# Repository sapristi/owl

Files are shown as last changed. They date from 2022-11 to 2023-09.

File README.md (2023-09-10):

# The Owl

the owl

The Owl is a 36-key (diodeless!), MX-spaced, wireless keyboard.

It was forked from the [rae-dux](https://github.com/andrewjrae/rae-dux) (itself inspired by the [Architeuthis Dux](https://github.com/tapioki/cephalopoda/tree/main/Architeuthis%20dux) ).

The main difference with the rae-dux is that MX-spacing is used for the keys. This keyboard is also designed with top and bottom plates, so as to protect the MCU and the battery. The mounting holes will fit m3 screws / standoffs.

**Note**: the top-plate doesn't need the mounting holes, so you could remove them from the kicad files.

## Art

The art for the keyboard is from vecteezy.com:
 - top was adapted from https://www.vecteezy.com/vector-art/2531138-black-and-white-line-art-of-owl
 - bottom was adapted from https://www.vecteezy.com/vector-art/3378572-barn-owl-flying-over-black-background

## Firmware

Since the keyboard is the same as the rae-dux, you can use the rae-dux firmware for it, see e.g.
- [my rae-dux ZMK config](https://github.com/sapristi/zmk-config-rae-dux)
- the original [rae-dux ZMK shield](https://github.com/andrewjrae/zmk-config/tree/development/config/boards/shields/rae_dux) (note: this is configured to use an older zmk version, with some bugs on mod-tap)

## Build Guide

Checkout the build-guide for the [rae-dux](./build_guide/index.md). The main difference is that the MCUs are mounted on the bottom of the PCBs.

A small thing you can change is also to put power switche on different sides of the pcb, so that both are in the same position for on-off.

## Important Notes
- **Wireless only**, the 36-key diodeless approach uses the P0 pin which is usually dedicated to TRRS
- There is only one MCU footprint, so **one controller has to be flipped**
- If you want to skip out on the switch, there is no jumper to use the JST
  connector, so you'll have to bodge a wire somewhere, or try shorting the
  switch footprint.

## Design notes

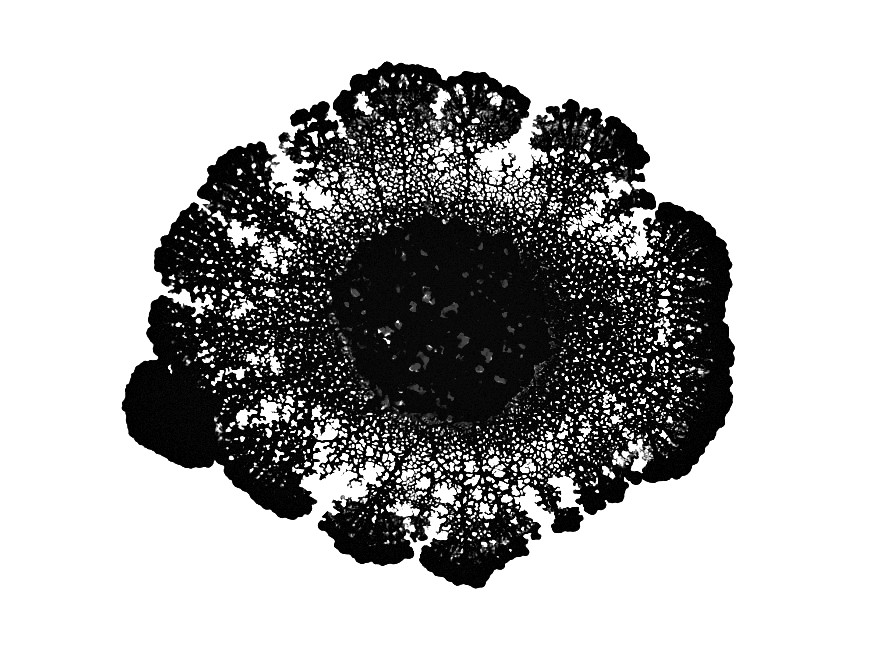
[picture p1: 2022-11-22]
images/blob.jpg

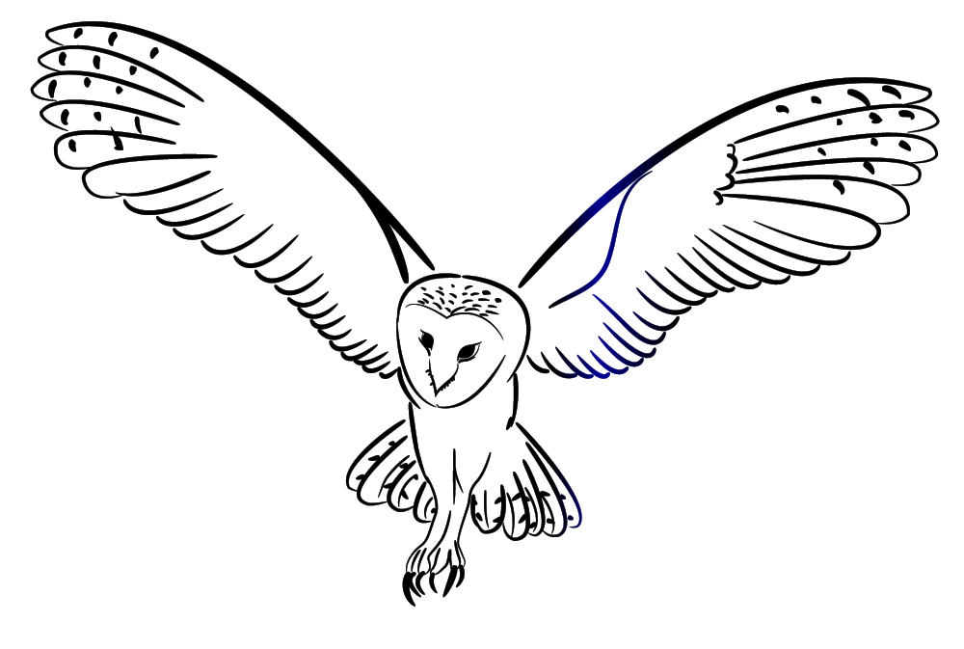
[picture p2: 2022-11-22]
images/owl_back.png

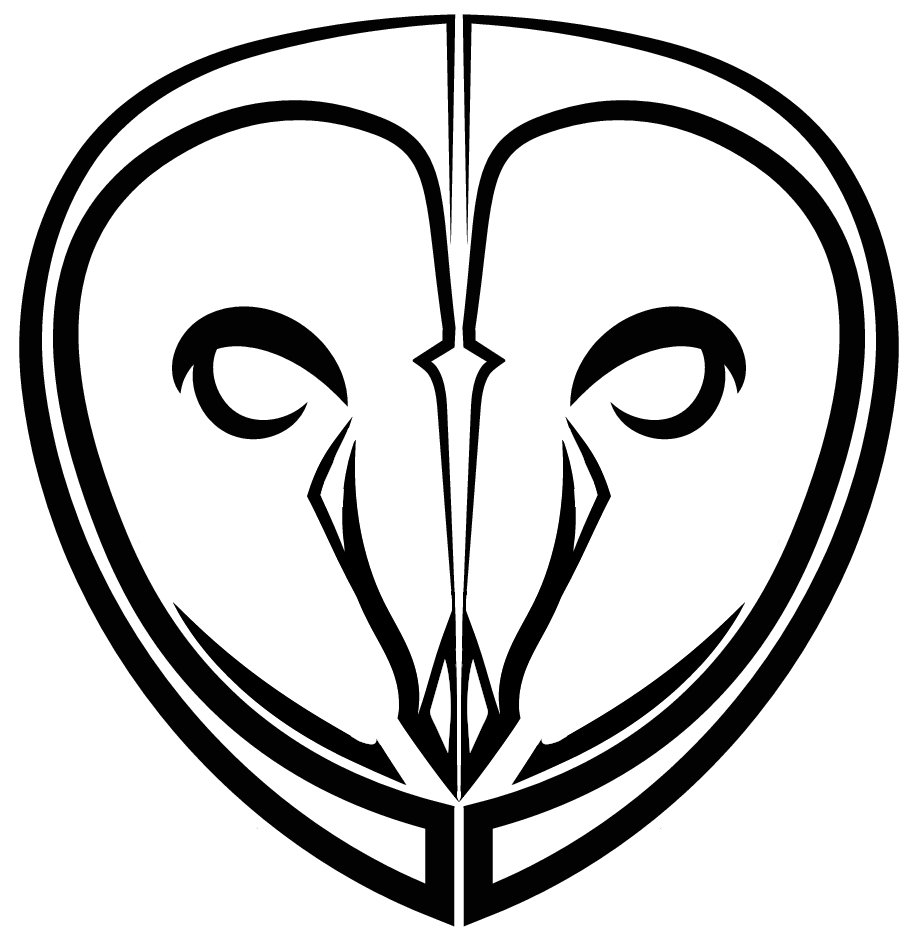
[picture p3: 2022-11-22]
images/owl_mini.png

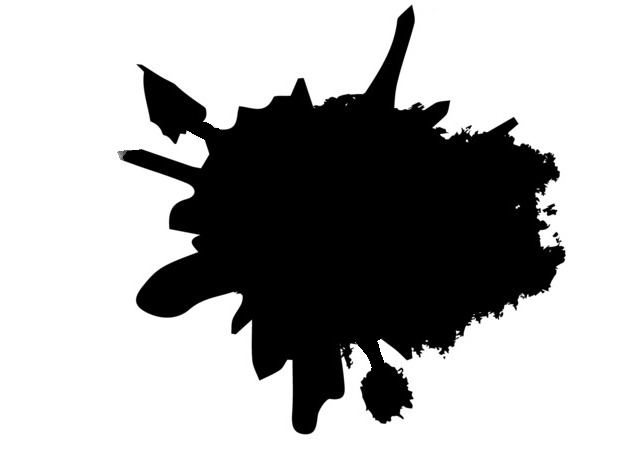
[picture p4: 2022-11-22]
images/blob_mini_1.jpg

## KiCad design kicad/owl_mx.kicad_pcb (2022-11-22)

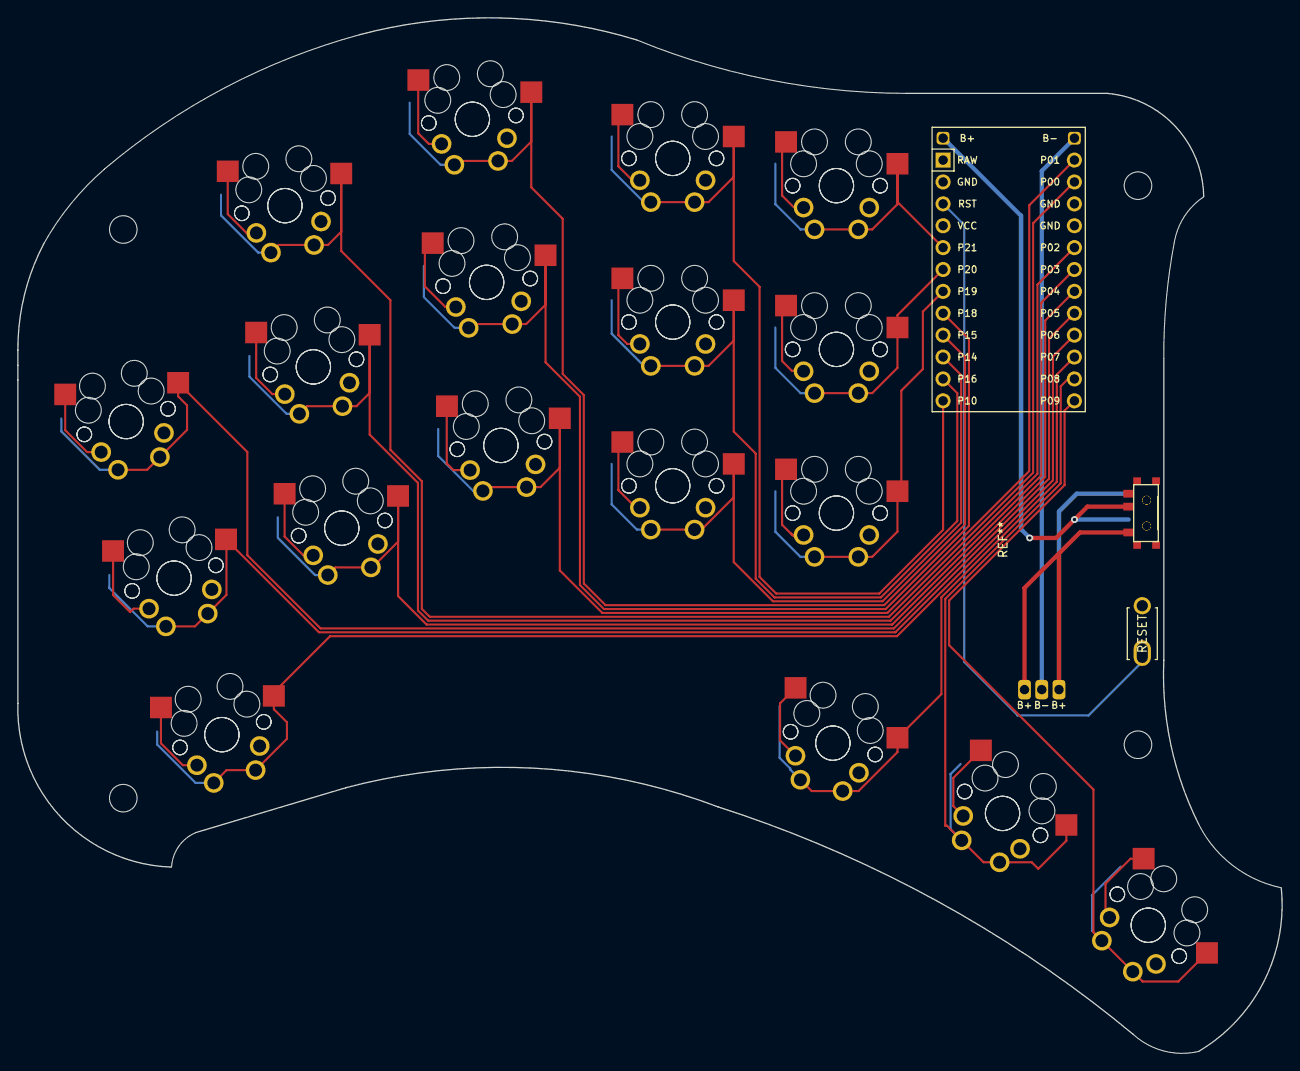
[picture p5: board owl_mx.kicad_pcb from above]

Board: 2 copper layers, 146.7 x 120.2 mm, 44 parts (0 on the bottom side), 22 nets.

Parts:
B1: ResetSW
MCU1: ProMicro
MOUNTING_PAD1, MOUNTING_PAD2, MOUNTING_PAD3, MOUNTING_PAD4: SMDPad
S1, S2, S3, S4, S5, S6, S7, S8, S9, S10, S11, S12, S13, S14, S15, S16, S17, S18, S19, S20, S21, S22, S23, S24, S25, S26, S27, S28, S29, S30, S31, S32, S33, S34, S35, S36: MX
T1, T2: SPDT_C128955

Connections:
Bplus: MCU1.25, T1.2, T2.2
Braw: T1.1, T2.1
GND: B1.2, MCU1.2, MCU1.15, MCU1.16, S1.2, S2.2, S3.2, S4.2, S5.2, S6.2, S7.2, S8.2, S9.2, S10.2, S11.2, S12.2, S13.2, S14.2, S15.2, S16.2, S17.2, S18.2, S19.2, S20.2, S21.2, S22.2, S23.2, S24.2, S25.2, S26.2, S27.2, S28.2, S29.2, S30.2, S31.2, S32.2, S33.2, S34.2, S35.2, S36.2
P0: MCU1.14, S11.1, S12.1
P1: MCU1.13, S13.1, S14.1
P2: MCU1.17, S9.1, S10.1
P3: MCU1.18, S7.1, S8.1
P4: MCU1.19, S5.1, S6.1
P5: MCU1.20, S3.1, S4.1
P6: MCU1.21, S1.1, S2.1
P7: MCU1.22, S31.1, S32.1
P8: MCU1.23, S33.1, S34.1
P9: MCU1.24, S35.1, S36.1
P10: MCU1.12, S23.1, S24.1
P14: MCU1.10, S19.1, S20.1
P15: MCU1.9, S17.1, S18.1
P16: MCU1.11, S21.1, S22.1
P18: MCU1.8, S15.1, S16.1
P19: MCU1.7, S25.1, S26.1
P20: MCU1.6, S27.1, S28.1
P21: MCU1.5, S29.1, S30.1
RST: B1.1, MCU1.3

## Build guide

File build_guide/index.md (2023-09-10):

# Rae-dux build guide

**Note**: this is a copy from the original build guide, that was hosted at https://www.tzcl.me/blog/rae-dux
You can still view the original at https://web.archive.org/web/20230202145801/https://www.tzcl.me/blog/rae-dux



## Overview

The rae-dux is a 36-key wireless ergo split keyboard designed by Andrew Rae. In my mind, it’s the perfect keyboard:

- I’ve found that 36 keys strikes the right balance for me – it feels great letting your index fingers and thumbs do most of the work.
- Going wireless has a lot of benefits, e.g., reducing clutter on your desk and allowing you to pair to your tablet or your phone.
- nice!nanos come with 18 pins so you can actually get away without using diodes (can connect all keys on each side directly to a pin).
- Low profile switches and keycaps feel super comfy and help give the board a small form factor, making it easy to pack away and carry with you.

If you’re interested in seeing how I use the rae-dux, my ZMK config is available here.

## Parts

- 2 x PCBs: see below on printing PCBs
- 2 x nice!nano: see https://nicekeyboards.com/nice-nano#find-a-store
- 2 x 3.7V 120mAh LiPo battery: should be stocked by most electronics stores
- 2 x right-angle JST-2 connector: should be stocked by most electronics stores
- 4 x 13 x female machined pin headers
- 56 x mill-max pins
- 2 x reset button: dimensions should be 6x3x4.3mm
- 2 x power switch: should have 7 pins
- 36 x kailh low-profile hotswap sockets
- 36 x choc switches
- 36 x choc keycaps
- 8 x rubber feet


## Getting PCBs printed

If you haven’t done it before, printing PCBs is simple. I use JLCPCB but there are a few similar services out there.

First, grab the gerbers from the repo. Then, navigate to https://cart.jlcpcb.com/quote and upload the gerber file. The settings are fine to leave as is, the main choices to make are whether you want a thinner PCB (1.2mm or 1.6mm are both fine) and what colour you want.

## Build guide

The build process is relatively straight forward as there’s no need to fiddle with tiny components like diodes and LEDs. The main thing is to double check which side of the PCBs is the front and which is the back. Getting this wrong will mean desoldering which is a pain in butt and can result in lifted pads if you aren’t careful. Better to get it right and not have to deal with any of that.

1. Solder on the hotswap sockets to the back of the left and right PCBs

The first step is soldering on the hotswap sockets. This is easiest to do while the board is flat and a good way to warm up if you’re new to soldering or haven’t soldered in a while. You can’t really mess this up, just make sure you pknow which PCB is going to be the left side of the board and which is going to be the right side, and make sure you solder the sockets on the back of the PCBs.

2. Solder on the reset buttons to the front of the PCBs
3. Solder on the JST connectors (be careful with the positioning)
4. Solder on the power switches

Next, we need to solder on the front-facing components. Like the hotswap sockets, you can’t really go wrong with soldering the reset buttons. A useful tip for these and for the JST connectors is to use some masking tape to hold them in place while you’re soldering. With the JST connectors, it’s important to place them in the right through-holes. The leftmost through-hole marked B+ shouldn’t be used, instead, the connectors should go into the B- and rightmost B+ holes. See the image below if you’re not sure. Finally, the sliding switches have 7 small pads so they are a little more difficult than the hotswap sockets. Take your time and reduce the heat of your soldering iron. It has two pins that fit into holes in the PCBs which should help keep them in place.

5. Break the female machined pin headers into four rows of 13
6. Solder the pin headers to the front of each PCB
7. Insert the mill-max pins into the pin headers
8. Put the nice!nanos in position and solder them to the mill-max pins (the left n!n should face down and the right n!n should face up)

The last step is socketing the nice!nanos. If you’ve never done this before, the splitkb.com docs have a good guide with pictures. Break off four rows of 13 of the female machined pin headers and solder them to the front of each PCB. Again, masking tape may come in handy. Once that’s done, insert the mill-max pins into the sockets and then put the nice!nanos into place. Make sure the left nice!nano should be flipped so the flat side (the back** is facing upwards. Then, solder the pins to the controllers. Be careful, take your time and reduce the heat of your soldering iron.

9. Lift the nice!nanos from the sockets, position the batteries between the pin headers and reseat the nice!nanos on top of the batteries

If all goes well, you should be able to gently rock the nice!nanos and lift them out of the sockets. Connect the batteries to the JST connectors and place them in between the sockets, underneath where the nice!nanos go. Now, you can push the nice!nanos back in and hopefully never need to remove them again.

At this stage, you should have something like this. Before installing all of your switches and keycaps, I recommend testing the board to make sure everything is working.



## Configuring ZMK

Now that you’ve built your keyboard, we want to make sure that things work before going through the effort of putting all your switches and keycaps in place. The simplest way to do that is to grab the firmware from my zmk-config. You can completely customise this if you want, you just need to make sure that you use the shield created by Andrew which isn’t available in the main ZMK repo at this point.

Once you’ve downloaded the firmware, you need to extract it. This should give you a folder with a bunch of .uf2 files.



To flash the nice!nanos, you need to hit the reset button twice to put them into bootloader mode. Starting with the left half, connect it to your computer using a USB-C cable and put it into booloader mode. Then, you should it pop up on your computer, where you need to copy and paste the left .uf2. After this, it should reboot and eject itself. Repeat this with the other half.


Once this is done, you should be able to go to the Bluetooth settings on your computer or phone and see ’rae-dux’. Connecting to this should let you see if your keyboard is correctly sending keystrokes.

Note, if you have the keyboard connected to your computer via a USB cable, it will communicate via that cable instead of by Bluetooth. Also, if you have issues getting your keyboard to connect, grab the settings_reset .uf2 file in the firmware folder and follow these steps to reset your split keyboard halves.

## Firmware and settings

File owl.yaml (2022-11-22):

units:
  kx: 19
  ky: 19
  px: 2
  py: 2
  decalage: 8
points:
  key:
    footprints:
      mx_hotswap:
        type: mx
        nets:
          from: =column_net
          to: GND
        params:
            keycaps: true
            reverse: true
            hotswap: true
      mx:
        type: mx
        anchor:
          rotate: 180
        nets:
          from: =column_net
          to: GND
        params:
            keycaps: true
            reverse: true
  zones:
    matrix:
      anchor:
        shift: [50, 50]
      key.padding: ky
      columns:
        pinky:
          spread: 18
          rotate: 17
          origin: [0, -ky]
          key:
            bind: [0.1, 0.5 kx, 0.1, 0.1]
          rows:
            bottom:
              column_net: P6
            home:
              column_net: P5
            top:
              column_net: P4
        ring:
          spread: 18
          stagger: ky
          rotate: -7
          origin: [0, -ky]
          key:
            bind: [0.1, 0.5 kx, 0.1, 0.1]
          rows:
            bottom:
              column_net: P3
            home:
              column_net: P2
            top:
              column_net: P0
        home:
          spread: 18
          stagger: ky/3
          rotate: -5
          origin: [0, -ky]
          key:
            bind: [0.1, 0.1, 0.5 kx, 0.1]
            shift: [0.2, 0]
          rows:
            bottom:
              column_net: P1
            home:
              column_net: P18
            top:
              column_net: P15
        index:
          spread: 18
          stagger: -ky/3
          rotate: -5
          origin: [0, -ky]
          key:
            bind: [0.1, 0.1, 0.5 kx, 0.5 kx]
          rows:
            bottom:
              column_net: P14
            home:
              column_net: P16
            top:
              column_net: P10
        inner:
          spread: 19
          stagger: -ky/6
          origin: [0, -ky]
          key:
            bind: [0.1, 0.1, 0.1, 0.5 kx]
          rows:
            bottom:
              column_net: P19
            home:
              column_net: P20
            top:
              column_net: P21
    thumbfan:
      anchor:
        ref: matrix_inner_bottom
        shift: [-1.10 kx, -1.0 ky]
      columns:
        near:
          spread: kx
          rotate: -15
          origin: [-1.5 kx, -0.5 ky]
          key:
            column_net: P7
        home:
          spread: kx
          rotate: -15
          origin: [-0.5 kx, -0.5 ky]
          key:
            column_net: P8
        far:
          spread: kx
          rotate: -15
          origin: [-0.5 kx, -0.5 ky]
          key:
            column_net: P9
      rows:
        thumb:
          row_net: P7
outlines:
  exports:
    raw:
      - type: keys
        side: left
        size: [kx + px, ky + py]
        corner: px
    thumbfan_glue:
      - type: polygon
        points:
          - ref: matrix_inner_home
          - ref: thumbfan_far_thumb
            shift: [0.5 kx - 0.5px, 0.5 ky + 0.5 py]
          - ref: thumbfan_far_thumb
            shift: [0.5 kx - 0.5px, -0.5 ky - 0.5 py]
          - ref: thumbfan_near_thumb
            shift: [-0.5 kx - px, -0.5 ky - py]
          - ref: matrix_pinky_bottom
            shift: [0.5 kx - 0.5 py, -0.5 ky - 0.5 py]
          - ref: matrix_pinky_home
          - ref: matrix_inner_bottom
            shift: [0.5 kx + 0.5px, -0.5 ky + 0.5 py]
    pinky_side:
      main:
        type: rectangle
        anchor:
          ref: matrix_inner_home
          shift: [-5kx, -3kx-1]
        size: [3kx, 4kx]
        corner: 10
    controller_area:
      main:
        type: rectangle
        anchor:
          ref:
            - matrix_inner_top
          shift: [0 kx, -4.05 ky]
        size: [30+decalage, 86.5]
        corner: px
    base_outline:
      main:
        type: outline
        name: raw
        fillet: 2
      thumbfan_glue:
        type: outline
        name: thumbfan_glue
        operation: add
      controller_area:
        type: outline
        name: controller_area
        operation: add
      pinky_side:
        type: outline
        name: pinky_side
        operation: add
    pcb:
      main:
        type: outline
        name: base_outline
        fillet: 15
    layout_tester:
      main:
        type: outline
        name: pcb
      keys:
        type: keys
        side: left
        size: [kx - 0.01, ky - 0.01]
        corner: px
        bound: false
        operation: subtract
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

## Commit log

2022-11-22 in progress
    [#owl_mx_top_plate-Edge_Cuts.dxf, board-routed_rounded.kicad_pcb, bottom.kicad_pcb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]
2023-01-01 gerbers and readme
2023-12-20 bottom gerbers
